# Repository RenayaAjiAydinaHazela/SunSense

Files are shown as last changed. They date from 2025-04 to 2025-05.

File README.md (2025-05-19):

# SunSense : Inovasi Jemuran Cerdas Otomatis untuk Rumah Tangga Modern

> *Matahari bisa absen kapan saja, tapi cucian tetap harus kering !!*
>

<aside>
⛅ Teknologi pintar yang mengikuti perubahan cuaca, menjaga jemuran Anda tetap aman di tengah kondisi tak menentu dan kesibukan yang tak bisa ditinggal

</aside>

## 💡 Tentang SunSense

**SunSense** adalah solusi inovatif untuk pengelolaan jemuran di rumah, mengintegrasikan teknologi otomatisasi dan sensor cerdas untuk menciptakan pengalaman yang lebih efisien, nyaman, dan ramah lingkungan. Dengan menggunakan mikrokontroler dan berbagai sensor, sistem ini dapat secara otomatis mengatur posisi jemuran berdasarkan kondisi cuaca terkini, memberikan kenyamanan ekstra bagi penggunanya.

Saat cuaca cerah dan kering, jemuran akan terbuka secara otomatis untuk mengeringkan pakaian. Sebaliknya, jika cuaca berubah menjadi mendung atau hujan, sistem akan menutup jemuran untuk melindungi pakaian dari hujan. Keunggulan dari **SunSense** adalah fleksibilitas yang diberikan kepada penggunanya; selain otomatis, sistem ini juga bisa dikendalikan secara manual melalui aplikasi atau tombol fisik, sehingga sesuai dengan preferensi pengguna.

Sebagai proyek open-source, **SunSense** terbuka untuk pengembangan lebih lanjut. Dengan pendekatan ini, sistem dapat beradaptasi dengan kebutuhan yang lebih beragam di masa depan, memberi peluang bagi para pengembang untuk berkontribusi dan memperkaya fungsionalitas sistem.

---

## 🎯 Visi dan Misi SunSense

### Visi

Menjadi solusi utama dalam kehidupan rumah tangga modern dengan menghadirkan sistem otomatisasi cerdas yang sederhana, hemat energi, dan mudah diakses oleh semua kalangan, sambil berfokus pada keberlanjutan dan inovasi teknologi.

### Misi

- **Inovasi Berkelanjutan:** Menghadirkan teknologi terbaru yang meningkatkan efisiensi, kenyamanan, dan kualitas hidup sehari-hari melalui otomatisasi rumah tangga.
- **Ramah Lingkungan:** Menyediakan solusi hemat energi yang dapat disesuaikan dengan penggunaan energi terbarukan, membantu rumah tangga mengurangi pemborosan energi.
- **Kolaborasi dengan Komunitas:** Mengembangkan SunSense sebagai proyek open-source yang dapat terus berkembang, dengan melibatkan komunitas untuk menciptakan solusi yang lebih baik dan lebih adaptif.
- **Menyederhanakan Kehidupan Rumah Tangga:** Memberikan kenyamanan lebih dengan otomatisasi jemuran yang merespons perubahan cuaca, sehingga pengguna dapat lebih fokus pada kegiatan mereka tanpa khawatir tentang cuaca yang berubah.
- **Mendorong Pengembangan Teknologi Cerdas:** Memperkenalkan dan memudahkan penerapan teknologi cerdas dalam kehidupan rumah tangga, mengubah rumah biasa menjadi rumah pintar yang lebih efisien dan fungsional.

Dengan pendekatan ini, **visi** dan **misi** SunSense menggabungkan konsep inovasi, ramah lingkungan, otomatisasi, dan kolaborasi komunitas, serta menyoroti pentingnya keberlanjutan dan penggunaan teknologi cerdas untuk meningkatkan kualitas hidup rumah tangga.

---

## 📌 Keunggulan SunSense

**SunSense** bukan hanya sekadar alat otomatis, tetapi sebuah solusi inovatif yang menggabungkan kecanggihan teknologi dan kenyamanan pengguna. Berikut adalah keunggulan utama dari **SunSense**:

1. **Automasi Cerdas yang Responsif**
    
    SunSense dilengkapi dengan sensor canggih yang dapat mendeteksi perubahan cuaca secara real-time. Sistem otomatis akan membuka jemuran saat cuaca cerah dan menutupnya secara otomatis saat hujan atau cuaca buruk, mengurangi kerepotan dalam mengatur jemuran secara manual.
    
2. **Kontrol Manual yang Fleksibel**
    
    Meskipun sepenuhnya otomatis, SunSense tetap memberi kebebasan kepada pengguna untuk mengatur jemuran secara manual kapan saja. Fitur kontrol manual ini memberikan fleksibilitas penuh, memungkinkan pengguna menyesuaikan pengaturan sesuai dengan kebutuhan atau situasi tertentu.
    
3. **Desain Modular dan Dapat Dikembangkan**
    
    SunSense dirancang dengan sistem modular yang memungkinkan pengguna atau pengembang untuk menyesuaikan atau mengembangkan sistem sesuai kebutuhan. Desain ini membuka peluang bagi integrasi dengan perangkat rumah pintar lainnya atau bahkan untuk penggunaan komersial di masa depan.
    
4. **Hemat Energi dan Ramah Lingkungan**
    
    Dengan konsumsi daya yang rendah, SunSense dirancang untuk efisiensi energi. Sistem ini dapat beroperasi dengan sumber daya minimal dan bahkan dapat terintegrasi dengan tenaga surya, menjadikannya pilihan yang lebih ramah lingkungan dan hemat biaya bagi rumah tangga.

Keunggulan-keunggulan ini menjadikan **SunSense** tidak hanya sebagai alat otomatis biasa, tetapi juga solusi yang memberikan kenyamanan lebih, efisiensi energi, dan fleksibilitas yang dapat berkembang sesuai kebutuhan pengguna.

---

## 📈 Potensi Pasar dan Peluang Investasi

**SunSense** memiliki potensi pasar yang besar dalam sektor rumah pintar (smart home) dan teknologi ramah lingkungan. Dengan semakin meningkatnya minat terhadap solusi rumah tangga yang otomatis dan efisien, **SunSense** siap memenuhi kebutuhan masyarakat yang menginginkan cara hidup yang lebih praktis, hemat energi, dan ramah lingkungan.

### Potensi Pasar:

1. **Rumah Tangga di Daerah Tropis atau Beriklim Tidak Menentu**
    
    Di wilayah yang sering mengalami cuaca tak menentu, seperti daerah tropis, **SunSense** akan sangat membantu dalam mengelola jemuran dengan efisien, menghindari kerugian akibat hujan mendadak, dan memastikan pakaian tetap kering tanpa harus tergantung pada cuaca.
    
2. **Layanan Laundry**
    
    Bisnis laundry dapat mengoptimalkan operasional mereka dengan menggunakan **SunSense**. Sistem otomatisasi ini memungkinkan pengelolaan jemuran yang lebih efisien, terutama untuk menanggulangi cuaca buruk, menghemat waktu, dan menjaga kualitas pakaian.
    
3. **Pengguna Rumah Pintar (Smart Homes)**
    
    **SunSense** sangat cocok untuk melengkapi ekosistem rumah pintar. Dengan teknologi otomatisasi yang dapat terintegrasi dengan perangkat rumah pintar lainnya, produk ini menawarkan kemudahan bagi pengguna yang ingin meningkatkan fungsionalitas dan efisiensi energi rumah mereka.
    
4. **Teknologi Hijau dan Energi Terbarukan**
    
    Dengan semakin tingginya kesadaran akan keberlanjutan, **SunSense** dapat menarik minat pasar yang peduli dengan solusi ramah lingkungan. Sistem yang hemat energi dan kompatibel dengan tenaga surya memberikan peluang untuk memperkenalkan teknologi hijau yang mengurangi pemborosan energi.

### Peluang Investasi:

**SunSense** bukan hanya solusi lokal, tetapi memiliki potensi besar untuk berkembang di pasar global. Seiring dengan tren meningkatnya adopsi rumah pintar dan teknologi ramah lingkungan, **SunSense** dapat meraih pangsa pasar yang lebih luas. Peluang investasi di sektor ini juga sangat menarik, karena adanya permintaan yang terus berkembang terhadap solusi yang mengintegrasikan teknologi pintar dengan kehidupan sehari-hari dan mendukung keberlanjutan.

Dengan pendekatan ini, **SunSense** tidak hanya menghadirkan inovasi yang berguna dalam kehidupan sehari-hari, tetapi juga membuka peluang besar untuk berkembang di pasar lokal dan internasional, sambil mendukung tren global menuju rumah pintar dan keberlanjutan energi.

---

## 🎓 In Collaboration With

**Dosen Pengampu :** 
Akhmad Hendriawan S.T., M.T.
197501272002121003

**Mata Kuliah :** 
Mikrokontroller

**Program Studi :** 
D4 Teknik Elektronika 

**Insititusi :** 
Politeknik Elektronika Negeri Surabaya

## 👥 Project Teams

| **NRP** | **Nama** | **Jobdesk** | **Akun** |
| --- | --- | --- | --- |
| 2123600036 | Diqta Putra Aditya |  |  |
| 2123600039 | Jonatan Arya Yoga Pratama |  |  |
| 2123600053 | Naufal Arif Zain |  |  |
| 2123600055 | Renaya Aji Aydina Hazela |  |  |
| 2123600060 | Rahma Aulia Hafidz |  |  |

---

## ✨ Mendukung Pengembangan Bersama

Sebagai proyek open-source, **SunSense** tidak hanya memberikan solusi inovatif bagi pengelolaan jemuran, tetapi juga menawarkan kesempatan bagi para pengembang, inovator, dan komunitas untuk berkolaborasi dalam menciptakan teknologi yang lebih canggih dan terintegrasi. Kolaborasi adalah kunci untuk menghasilkan solusi yang lebih baik, efisien, dan dapat diakses oleh lebih banyak orang.

Dengan mengadopsi prinsip open-source, kami mengundang Anda untuk menjadi bagian dari perjalanan ini, berkontribusi dalam pengembangan **SunSense**, dan membantu mempercepat penerapannya di berbagai sektor kehidupan, mulai dari rumah tangga hingga industri yang membutuhkan solusi efisien dan ramah lingkungan. Semua kontribusi, baik berupa kode, ide, ataupun investasi, akan memperkuat misi kami untuk menciptakan rumah tangga yang lebih efisien dan ramah lingkungan.

### Open-Source dan Kolaborasi Pengembangan

Kami percaya bahwa inovasi terbaik lahir dari kolaborasi. Oleh karena itu, **SunSense** dikembangkan dengan prinsip open-source, memberikan kesempatan kepada pengembang, akademisi, dan para hobiis untuk berkontribusi dalam memperkaya fungsionalitas dan penerapan sistem ini. Dengan pendekatan ini, kami membuka peluang bagi berbagai pihak untuk:

1. **Meningkatkan Fitur**
    
    Pengembang dapat menambahkan fitur baru seperti integrasi dengan perangkat IoT lainnya, atau pengembangan fungsionalitas tambahan yang mendukung kebutuhan rumah tangga modern.
    
2. **Memodifikasi Sistem**
    
    **SunSense** dirancang agar dapat disesuaikan dengan kebutuhan lokal maupun perkembangan teknologi baru. Kontribusi dalam modifikasi sistem akan memungkinkan adaptasi yang lebih luas dan lebih relevan di berbagai lingkungan.
    
3. **Mendorong Inovasi**
    
    Melalui kolaborasi dengan berbagai pihak, baik itu profesional, akademisi, maupun pengembang independen, kami dapat mempercepat proses inovasi dan penerapan teknologi yang ramah lingkungan dan efisien.

Kami mengundang para profesional, pengembang, dan inovator untuk bergabung dalam ekosistem **SunSense**. Bersama-sama, kita dapat menciptakan masa depan rumah tangga yang lebih cerdas, efisien, dan ramah lingkungan.

Dengan pendekatan ini, **SunSense** tidak hanya berfungsi sebagai solusi otomatisasi jemuran, tetapi juga sebagai platform terbuka untuk pengembangan bersama, membuka peluang bagi kolaborasi yang lebih luas dalam menghadirkan teknologi yang lebih baik dan lebih bermanfaat bagi masyarakat.

---

## 📞 Bergabunglah dengan Kami

**SunSense** lebih dari sekadar proyek teknologi, tetapi juga peluang untuk berinvestasi dalam menciptakan masa depan rumah tangga yang lebih cerdas, efisien, dan ramah lingkungan. Kami percaya bahwa kolaborasi adalah kunci untuk membawa inovasi ini ke lebih banyak rumah di seluruh dunia.

Jika Anda tertarik untuk berinvestasi, menjadi mitra, atau sekadar ingin mengetahui lebih banyak tentang **SunSense**, jangan ragu untuk menghubungi kami. Bersama-sama, kita dapat menghadirkan solusi rumah tangga yang lebih praktis dan terhubung dengan teknologi canggih, mendukung keberlanjutan dan efisiensi energi.

Mari wujudkan masa depan rumah tangga yang lebih pintar dan ramah lingkungan dengan bergabung bersama kami. Hubungi kami untuk lebih lanjut dan ambil bagian dalam revolusi rumah tangga pintar.

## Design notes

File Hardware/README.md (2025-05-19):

# 🌞 Hardware SunSense

SunSense dikembangkan sebagai sistem pintar yang mampu merespons kondisi lingkungan secara real-time melalui sensor cahaya, hujan, suhu, dan kelembapan. Dengan memanfaatkan Arduino Nano sebagai otak utama dan modul komunikasi Bluetooth HC-05, proyek ini dirancang untuk memberikan solusi otomatisasi jemuran berbasis cuaca yang praktis dan efisien. 

Sistem ini tidak hanya dapat memantau, tetapi juga melakukan aksi langsung melalui motor servo yang dikendalikan otomatis sesuai data sensor. Pendekatan desain yang kompak, modular, dan berbasis user-experience menjadikan SunSense ideal untuk diterapkan dalam rumah tangga cerdas maupun pengembangan teknologi IoT skala kecil.

---

## ⚙️ Spesifikasi Hardware

| **Komponen** | **Tipe** | **Fungsi** |
| --- | --- | --- |
| **Mikrokontroler** | Arduino Nano | Mikrokontroler utama yang mengelola seluruh proses logika, pengambilan keputusan berdasarkan input sensor. |
| **Sensor Cahaya** | LDR | Mendeteksi intensitas pencahayaan matahari. Digunakan untuk memutuskan kapan jemuran boleh terbuka. |
| **Sensor Hujan** | FC-37 (Rain Drop) | Menentukan keberadaan air/hujan melalui hambatan listrik. Jika mendeteksi hujan (basah), sistem menutup jemuran. |
| **Sensor Suhu**  | DHT22 | Memberikan data suhu dan kelembapan lingkungan sebagai informasi tambahan untuk mengatur kondisi optimal pengeringan. |
| **Motor Servo** | SG90 | Aktuator untuk menggerakkan mekanisme buka-tutup jemuran secara otomatis. |
| **Driver Motor** | L298N | Mengatur suplai daya dan sinyal kontrol ke motor dari mikrokontroler. |
| **Regulator Tegangan** | L7805 | Mengatur dan menstabilkan tegangan 5V dari sumber daya eksternal ke komponen seperti mikrokontroler dan sensor. |
| **Bluetooth Module** | HC-05 | Komunikasi serial jarak dekat untuk kontrol manual dan monitoring via aplikasi mobile. |
| **Power Supply (Baterai)** | Ultrafire 18650A 3000mAh | Menyediakan daya untuk menggerakkan motor dan sistem kontrol secara keseluruhan. |
| **PCB** | Single Layer | Menyusun dan menyambungkan seluruh rangkaian elektronik secara rapi dan terorganisir. |
| **Bearing / Pulley** | - | Mendukung gerakan mekanik agar lebih halus, stabil, dan minim gesekan. |

---

## 📌 Diagram Pin Arduino

| Perangkat | Pin Arduino Nano | Jenis Pin | Keterangan |
| --- | --- | --- | --- |
| LDR | A1 | Analog | Sensor cahaya |
| FC-37 (Sensor Hujan) | D8 | Digital | Sensor hujan |
| DHT22 | D6 | Digital | Suhu & kelembapan |
| Servo Motor | D7 | PWM | Kendali aktuator |
| HC-05 Bluetooth | D0 (TX), D1 (RX) | UART | Komunikasi Serial |

---

## 🔌 Deskripsi Pin dan Fungsi

### 🟢 GPIO Output

### 🧭 Servo Motor

Motor servo dikendalikan melalui **pin D5** menggunakan sinyal **PWM (Pulse Width Modulation)** dari Arduino. Pergerakan servo digunakan untuk **mengoperasikan mekanisme buka-tutup jemuran** secara presisi dan otomatis. Keputusan penggerakan servo didasarkan pada hasil analisis data dari sensor lingkungan, seperti hujan, suhu, dan intensitas cahaya, guna memastikan jemuran hanya terbuka pada kondisi cuaca yang aman dan optimal.

---

### 🔁 UART Communication

### 📶 HC-05 (Bluetooth Module)

Modul HC-05 dihubungkan ke pin **D0 (TX)** dan **D1 (RX)** Arduino, memungkinkan komunikasi **serial dua arah** antara sistem dan aplikasi pada perangkat seluler. Modul ini berfungsi sebagai antarmuka **nirkabel** yang memudahkan pengguna untuk **memantau status sensor secara real-time** serta **mengontrol sistem jemuran otomatis** langsung dari jarak dekat melalui koneksi Bluetooth. Integrasi ini meningkatkan fleksibilitas dan kemudahan dalam pengoperasian sistem.

---

### 📥 Analog Input

### 🟡 LDR (Light Dependent Resistor)

Sensor LDR terhubung ke pin **A1** dan menghasilkan sinyal **analog** yang merepresentasikan intensitas pencahayaan lingkungan. Arduino membaca perubahan tegangan dalam rentang **0–5V** dan menginterpretasikannya sebagai indikator cuaca cerah atau mendung. Nilai ini digunakan sistem untuk membantu menentukan apakah jemuran otomatis perlu **dibuka atau ditutup**, berdasarkan ambang batas pencahayaan yang telah diprogram

### 📥 Digital Input

---

### 🌧️ FC-37 (Sensor Hujan)

Sensor hujan FC-37 dihubungkan ke pin **D8** dan memberikan sinyal digital berupa **HIGH** atau **LOW** berdasarkan kondisi permukaan sensornya. Ketika permukaan sensor dalam kondisi **basah**, output akan **LOW**, dan ketika **kering**, output akan **HIGH**. Informasi ini digunakan sistem sebagai indikator otomatis untuk mendeteksi keberadaan hujan dan mengaktifkan mekanisme penutupan jemuran.

### 🌡️ DHT22 (Sensor Suhu & Kelembapan)

Terhubung ke pin **D6**, sensor DHT22 menggunakan protokol komunikasi **single-wire (*One-Wire*)** untuk mengirimkan data suhu dan kelembapan secara berkala. Informasi lingkungan ini menjadi parameter pendukung yang penting dalam sistem pengambilan keputusan, guna memastikan proses pengeringan berjalan pada kondisi yang optimal dan efisien.

---

## 📦 Library Arduino

Instal melalui Library Manager di Arduino IDE:

- `DHT sensor library`
- `Adafruit Unified Sensor`
- `Servo.h` – Tersedia secara default di Arduino IDE

---

## 🏷️ Lisensi

Proyek ini merupakan inovasi berbasis mikrokontroler yang dikembangkan secara mandiri oleh mahasiswa **Electronic Engineering Polytechnic Institute of Surabaya (EEPIS)** untuk menjawab kebutuhan otomatisasi rumah tangga yang cerdas dan efisien. 
SunSense dirancang dengan pendekatan teknis yang solid, menggunakan sensor cuaca dan aktuator presisi untuk mendeteksi kondisi lingkungan secara real-time dan mengoperasikan sistem jemuran otomatis.

Proyek ini terbuka untuk dikembangkan lebih lanjut dan dapat dimodifikasi untuk kebutuhan komersial maupun edukatif, selama tetap mencantumkan sumber. Dengan pendekatan modular, efisien, dan berbasis data, SunSense menjadi solusi potensial dalam pengembangan smart home berbasis teknologi lokal yang scalable dan dapat diandalkan.

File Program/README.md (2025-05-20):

# 🌤️ **Program SunSense**

## 📋 **Deskripsi Program Simulasi**

Program ini merupakan bagian dari pengembangan sistem **SunSense**, yaitu solusi jemuran cerdas yang mampu beradaptasi terhadap kondisi lingkungan secara **otomatis maupun manual** menggunakan platform mikrokontroler **Arduino Nano**.

Simulasi ini dibangun di **Wokwi**, sebuah simulator online berbasis Arduino, dengan tujuan untuk **mengujicoba logika dan alur kerja sistem** sebelum diterapkan ke perangkat keras sesungguhnya.

Beberapa komponen fisik digantikan dengan **potensiometer** dan **push button** agar fleksibel dalam pengujian berbagai skenario lingkungan seperti suhu tinggi, cahaya rendah, atau kondisi hujan.

> Fokus utama simulasi: Menguji keakuratan pengambilan keputusan, kestabilan logika servo, serta validitas data yang dikirim via komunikasi serial.
> 

---

## 🗂️ **Struktur Program**

- **🔬 Program Simulasi (Prototype Virtual)**
    
    Menggunakan komponen pengganti untuk mencerminkan perilaku sensor asli. Simulasi ini menguji logika pengendalian servo dan pengambilan keputusan berdasarkan parameter lingkungan.
    
- **🔧 Program Asli Hardware (Final Deployment)** 
    
    Dirancang untuk implementasi fisik dengan koneksi sensor dan aktuator asli, termasuk penggunaan **DHT22**, **FC-37**, **LDR**, serta **HC-05** untuk integrasi mobile app melalui Bluetooth.

---

## 🛠️ **Komponen Simulasi di Wokwi**

| Komponen | Fungsi | Keterangan |
| --- | --- | --- |
| **Potensiometer 1** | Simulasi suhu lingkungan | Output analog dikonversi menjadi nilai suhu (rentang 0–50°C) |
| **Potensiometer 2** | Simulasi intensitas cahaya | Mewakili nilai dari sensor LDR, digunakan untuk deteksi siang/malam |
| **Potensiometer 3** | Simulasi kelembapan udara | Input analog dikonversi menjadi % kelembapan |
| **Push Button 1** | Simulasi kondisi hujan | Nilai LOW = hujan; HIGH = tidak hujan |
| **Push Button 2** | Pergantian mode otomatis <-> manual | Ditekan sekali untuk mengubah mode kerja |
| **Push Button 3** | Kontrol manual jemuran | Aktif hanya saat berada di mode manual |
| **Servo Motor** | Simulasi aktuator penggerak jemuran | Digerakkan ke posisi 0° (masuk) atau 45° (keluar) |

> Kombinasi potensiometer dan tombol memungkinkan simulasi dinamis terhadap perubahan lingkungan dan intervensi pengguna.
> 

---

## 🔌 **Konfigurasi Pin: Simulasi vs Hardware**

### 🔧 Simulasi (Wokwi)

| Perangkat Simulasi | Pin Arduino | Tipe Pin | Fungsi dalam Simulasi |
| --- | --- | --- | --- |
| Potensiometer 1 | A0 | Analog | Suhu |
| Potensiometer 2 | A1 | Analog | Cahaya (LDR) |
| Potensiometer 3 | A2 | Analog | Kelembapan |
| Push Button 1 (Biru) | D2 | Digital | Hujan |
| Push Button 2 (Merah) | D3 | Digital | Ganti mode |
| Push Button 3 (Hijau)| D4 | Digital | Kontrol manual |
| Servo Motor | D5 | PWM | Aktuator jemuran |

### ⚙️ Hardware (Final)

| Perangkat Asli | Pin Arduino Nano | Tipe Pin | Keterangan |
| --- | --- | --- | --- |
| LDR (Sensor Cahaya) | A1 | Analog | Mengukur intensitas pencahayaan |
| FC-37 (Sensor Hujan) | D8 | Digital | Deteksi permukaan basah/kering |
| DHT22 | D6 | Digital | Mengukur suhu & kelembapan |
| Servo Motor | D7 | PWM | Menggerakkan mekanisme jemuran |
| HC-05 Bluetooth | D0 (TX), D1 (RX) | UART | Komunikasi dengan mobile app |

---

## 🧠 **Alur Logika Program**

Alur program pada sistem SunSense terbagi menjadi **5 tahap utama** yang berlangsung secara berulang (loop) selama sistem berjalan. Masing-masing tahap dijelaskan lebih detail berikut ini:

---

### 🟢 **1. Pembacaan Sensor Simulasi**

Sistem membaca data dari tiga potensiometer sebagai pengganti sensor fisik:

- **Potensiometer 1 (A0):**
    - Disimulasikan sebagai **suhu lingkungan**.
    - Nilai analog (0–1023) dikonversi ke skala suhu (sekitar 0–50°C) menggunakan rumus linear.
    - Tujuannya untuk meniru pembacaan dari sensor **DHT22** atau **LM35**.
- **Potensiometer 2 (A1):**
    - Disimulasikan sebagai **intensitas cahaya** (LDR).
    - Nilai analog tinggi → cahaya terang, nilai rendah → cahaya gelap.
    - Threshold digunakan untuk menentukan siang atau malam.
- **Potensiometer 3 (A2):**
    - Disimulasikan sebagai **kelembapan udara**.
    - Dikonversi ke skala kelembapan (0–100%).
    - Mewakili kemampuan udara untuk menahan uap air, berkaitan dengan potensi hujan atau penguapan.

🔄 *Pembacaan dilakukan secara terus-menerus setiap siklus loop untuk menangkap perubahan kondisi lingkungan secara real time.*

---

### 🟨 **2. Pembacaan Input Push Button**

Sistem menggunakan **tiga push button digital** untuk mengontrol dan menyimulasikan peristiwa:

- **Push Button 1 (D2) – Deteksi Hujan:**
    - Jika ditekan (LOW), maka sistem mendeteksi bahwa **hujan sedang turun**.
    - Jika tidak ditekan (HIGH), maka cuaca dianggap **kering**.
    - Ini meniru pembacaan digital dari sensor **FC-37** yang mendeteksi tetesan air.
- **Push Button 2 (D3) – Toggle Mode Otomatis/Manual:**
    - Menekan tombol ini akan **mengubah mode kerja** sistem secara *toggle*:
        - Jika sebelumnya **otomatis**, maka berubah ke **manual**.
        - Jika sebelumnya **manual**, kembali ke **otomatis**.
    - Digunakan `flag` (variabel penanda) untuk menyimpan status mode saat ini.
- **Push Button 3 (D4) – Kontrol Manual:**
    - Hanya aktif saat berada dalam **mode manual**.
    - Jika ditekan → jemuran **keluar** (servo ke 45°).
    - Jika dilepas → jemuran **masuk** (servo ke 0°).
    - Simulasi ini memberi pengguna kontrol langsung atas jemuran, seperti **override** otomatis.

---

### 🟧 **3. Logika Keputusan Sistem (Decision Making)**

### 🔁 **Jika Mode Otomatis Aktif:**

Sistem akan **menganalisis parameter lingkungan** untuk menentukan apakah jemuran sebaiknya dikeluarkan atau dimasukkan:

| Parameter | Nilai Ideal | Keterangan |
| --- | --- | --- |
| Suhu | > 30°C | Semakin tinggi suhu, semakin baik untuk pengeringan pakaian |
| Cahaya | > 300 (dari 1023) | Menandakan siang hari (terang), cocok untuk menjemur |
| Kelembapan | < 80% | Kelembapan rendah → udara kering → mempercepat pengeringan |
| Deteksi Hujan | Tidak hujan (HIGH) | Jika ada hujan → jemuran wajib masuk tanpa mempedulikan parameter lain |

**Logika gabungan (AND):**

```c
if (suhu > 30 && cahaya > 300 && kelembapan < 80 && !hujan) {
    // jemuran keluar
} else {
    // jemuran masuk
}
```

📌 **Catatan penting:**

Jika **salah satu saja** dari syarat di atas tidak terpenuhi, sistem akan memutuskan untuk **memasukkan jemuran** demi keamanan.

---

### ⛔ **Jika Mode Manual Aktif:**

- Sistem **mengabaikan semua data sensor**, termasuk deteksi hujan.
- **Keputusan hanya diambil dari tombol push button 3:**
    - Tekan → jemuran keluar.
    - Lepas → jemuran masuk.
- Cocok untuk kondisi tertentu di mana pengguna ingin mengambil alih kontrol sepenuhnya (misalnya, menjemur sepatu atau pakaian khusus dalam cuaca ekstrem tapi mendesak).

---

### 🟦 **4. Pengendalian Aktuator (Servo Motor)**

Servo motor digunakan untuk mensimulasikan pergerakan jemuran dengan dua posisi utama:

| Posisi Servo | Sudut | Aksi Jemuran |
| --- | --- | --- |
| 0° | MINIMAL | Jemuran masuk |
| 45° | TERBUKA | Jemuran keluar |

### 🔄 Alur Pengendalian:

- Program hanya akan **menggerakkan servo** jika posisi saat ini berbeda dari posisi sebelumnya untuk menghindari getaran servo yang tidak perlu (hemat energi & memperpanjang umur servo).

```c
if (statusSekarang != statusSebelumnya) {
   servo.write(sudutBaru);
}
```

---

### 📤 **5. Pengiriman Data ke Serial Monitor**

Semua data penting akan ditampilkan di **Serial Monitor** untuk tujuan debugging, pemantauan, dan dokumentasi logika sistem.

**Data yang dikirim meliputi:**

- Nilai suhu dalam °C
- Nilai kelembapan dalam %
- Nilai cahaya (0–1023)
- Status hujan (Ya/Tidak)
- Mode aktif (Otomatis/Manual)
- Aksi jemuran (Keluar/Masuk)

📦 Format contoh di Serial Monitor:

```
Mode: Otomatis
Suhu: 32.5 °C
Kelembapan: 65.3 %
Cahaya: 540
Status Hujan: Tidak
Jemuran: Keluar
-----------------------------
```
Data ini juga dapat dimanfaatkan pada tahap selanjutnya untuk **dikirim ke aplikasi mobile** via Bluetooth HC-05 dalam implementasi hardware.

---

## 🔍 **Threshold Logika Otomatis (Contoh)**

| Parameter | Ambang Batas | Keputusan Sistem |
| --- | --- | --- |
| Suhu | > 30°C | Jemuran dapat keluar |
| Intensitas Cahaya | > 300 (analog) | Siang, jemuran dapat keluar |
| Kelembapan | < 80% | Aman untuk menjemur |
| Status Hujan | Tidak hujan | Jemuran dapat keluar |

> Jika salah satu parameter tidak memenuhi, jemuran akan masuk otomatis untuk perlindungan.
> 

---

## 📡 **Integrasi ke Perangkat Mobile (Tahap Hardware)**

- Komunikasi dua arah menggunakan **HC-05 Bluetooth**.
- Data suhu, kelembapan, kondisi hujan, dan status jemuran ditampilkan di aplikasi mobile.
- Pengguna juga bisa mengganti mode dan mengontrol jemuran dari aplikasi.

---

## 💻 **Simulasi Online**
   
   👉 [Klik di sini untuk membuka simulasi di Wokwi](https://wokwi.com/projects/429473945254121473)

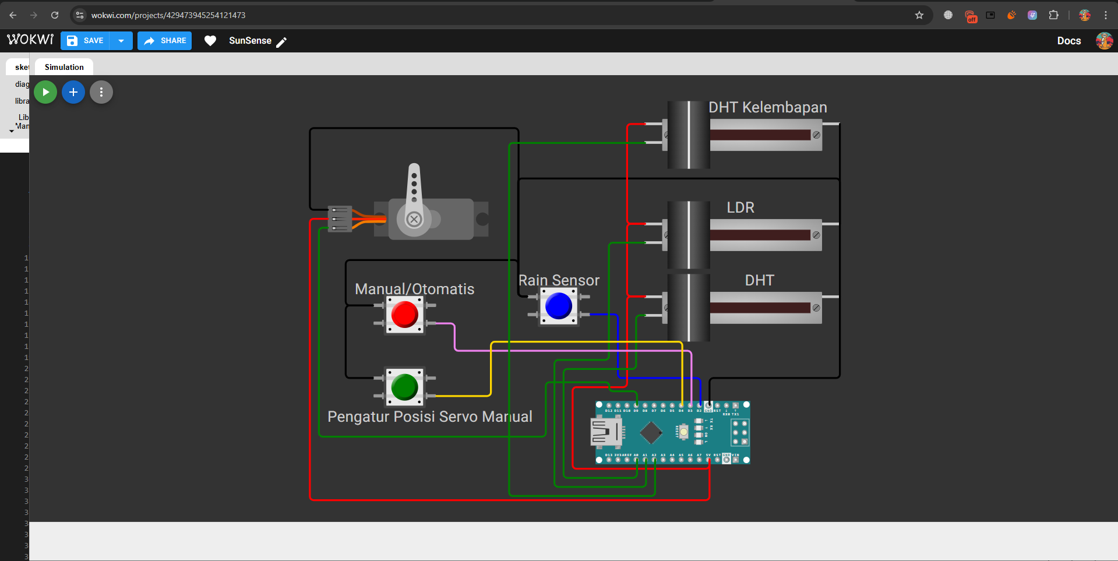
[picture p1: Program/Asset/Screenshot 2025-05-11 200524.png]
  
  
---

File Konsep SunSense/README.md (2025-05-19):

# ⛅ Konsep SunSense

SunSense adalah solusi cerdas untuk aktivitas menjemur pakaian yang menggabungkan teknologi otomasi dengan responsivitas terhadap cuaca secara *real-time*. Dirancang untuk merespons tantangan harian seperti hujan mendadak atau cuaca tak menentu, sistem ini secara otomatis membuka dan menutup jemuran sesuai kondisi lingkungan, tanpa perlu intervensi pengguna.

Lebih dari sekadar alat bantu, SunSense membawa pendekatan baru dalam mengelola rutinitas rumah tangga secara lebih **efisien, praktis, dan modern**. Sistem ini dikembangkan sebagai jawaban atas kebutuhan gaya hidup yang semakin dinamis, di mana waktu, kenyamanan, dan ketepatan menjadi prioritas.

Dengan desain yang dapat diadaptasi untuk skala rumah tangga maupun kebutuhan komersial seperti usaha laundry, SunSense menawarkan lebih dari kemudahan. Kehadiran SunSense akan  menjadi bagian dari transformasi menuju **rumah pintar** (*smart living*) yang berdaya guna dan hemat energi.

Konsep ini juga terbuka untuk pengembangan lebih lanjut, seperti integrasi dengan Internet of Things (IoT) dan kontrol berbasis aplikasi, menjadikannya fleksibel untuk masa kini dan siap menghadapi kebutuhan masa depan.

---

## ⚙️ Komponen Utama Sistem SunSense

SunSense dibangun dari serangkaian komponen utama yang saling terintegrasi dan memiliki peran spesifik dalam mendeteksi, mengolah, serta merespons kondisi cuaca. Setiap komponen dipilih berdasarkan pertimbangan efisiensi, kinerja, dan kemudahan integrasi, sehingga sistem tidak hanya bekerja optimal, tetapi juga mudah dikembangkan lebih lanjut.

| **Komponen** | **Tipe** | **Fungsi** | Harga |
| --- | --- | --- | --- |
| **Mikrokontroler** | Arduino Nano | Mikrokontroler utama yang mengelola seluruh proses logika, pengambilan keputusan berdasarkan input sensor. |  |
| **Sensor Cahaya** | LDR | Mendeteksi intensitas pencahayaan matahari. Digunakan untuk memutuskan kapan jemuran boleh terbuka. | 10.000 |
| **Sensor Hujan** | FC-37 (Rain Drop) | Menentukan keberadaan air/hujan melalui hambatan listrik. Jika mendeteksi hujan (basah), sistem menutup jemuran. | 20.000 |
| **Sensor Suhu**  | DHT22 | Memberikan data suhu dan kelembapan lingkungan sebagai informasi tambahan untuk mengatur kondisi optimal pengeringan. | 15.000 |
| **Motor Servo** | SG90 | Aktuator untuk menggerakkan mekanisme buka-tutup jemuran secara otomatis. | 50.000 |
| **Driver Motor** | L298N | Mengatur suplai daya dan sinyal kontrol ke motor dari mikrokontroler. | 25.000 |
| **Regulator Tegangan** | L7805 | Mengatur dan menstabilkan tegangan 5V dari sumber daya eksternal ke komponen seperti mikrokontroler dan sensor. | 50.000 |
| **Bluetooth Module** | HC-05 / HC-06 | Komunikasi serial jarak dekat untuk kontrol manual dan monitoring via aplikasi mobile. | 40.000 |
| **Power Supply** | - | Menyediakan daya untuk menggerakkan motor dan sistem kontrol secara keseluruhan. | 50.000 |
| **PCB** | - | Menyusun dan menyambungkan seluruh rangkaian elektronik secara rapi dan terorganisir. | 20.000 |
| **Bearing / Pulley** | - | Mendukung gerakan mekanik agar lebih halus, stabil, dan minim gesekan. |  |

Tak hanya berfokus pada kecanggihan sensor dan kendali otomatis, SunSense juga mengedepankan stabilitas sistem secara menyeluruh. Desainnya memperhatikan keteraturan sirkuit elektronik agar lebih aman dan efisien, sekaligus memastikan pergerakan mekanik berjalan dengan lancar tanpa hambatan berarti. 

Sistem penggeraknya didukung oleh komponen perantara yang menjamin instruksi dari unit kendali dapat diterjemahkan dengan presisi ke gerakan fisik yang diharapkan. Kombinasi antara aspek elektronik dan mekanik ini menjadikan SunSense tidak hanya andal, tetapi juga siap untuk dikembangkan ke skala lebih besar.

---

## 📋 Komunikasi Sistem

Agar dapat bekerja secara otomatis namun tetap adaptif terhadap kebutuhan pengguna, sistem SunSense mengandalkan skema komunikasi data yang tertata antara berbagai komponen internal maupun eksternal. Komunikasi ini mencakup tiga jalur utama: sensor ke mikrokontroler, mikrokontroler ke aktuator, serta mikrokontroler ke pengguna. Masing-masing jalur memiliki karakteristik dan fungsi tersendiri yang saling terintegrasi dalam kerangka kendali tertanam (*embedded control system*).

### Sensor ke Mikrokontroler (*One-Way Input*)

Sensor-sensor lingkungan berfungsi sebagai “mata dan telinga” sistem, memberikan informasi aktual terkait kondisi sekitar secara real-time. Komunikasi dari sensor ke mikrokontroler bersifat satu arah, di mana sensor mengirimkan sinyal:

- **Analog**, seperti pada sensor cahaya (LDR) atau sensor suhu, yang mengirimkan nilai kontinu untuk merepresentasikan intensitas cahaya atau suhu ruangan.
- **Digital**, seperti pada sensor hujan, yang memberikan status biner (hujan atau tidak) sebagai logika keputusan cepat.

Mikrokontroler kemudian membaca data ini melalui pin analog atau digital, lalu mengolahnya untuk menentukan kondisi cuaca saat itu.

### Mikrokontroler ke Aktuator (*One-Way Output*)

Setelah data dari sensor diproses dan dikonversi menjadi instruksi, mikrokontroler mengirimkan perintah kepada aktuator (motor penggerak) untuk mengeksekusi tindakan fisik. Komunikasi ini juga bersifat satu arah, dengan pola sebagai berikut:

- **Sinyal PWM (Pulse Width Modulation)** digunakan untuk mengatur kecepatan atau posisi motor, tergantung jenis motor yang digunakan (servo atau DC).
- **Transmisi sinyal logika melalui driver** untuk memastikan arus dan tegangan sesuai kebutuhan aktuator, menjaga keamanan rangkaian dan efektivitas perintah.

Perintah yang dikirim bisa berupa instruksi membuka atau menutup jemuran, tergantung pada hasil analisis kondisi cuaca.

### Mikrokontroler ke Pengguna (Two-*Way*)

Salah satu nilai tambah SunSense adalah kemampuannya untuk tetap terkoneksi dengan pengguna melalui jalur komunikasi eksternal berbasis Bluetooth. Jalur ini memungkinkan komunikasi dua arah:

- **Arah keluar (output):** Mikrokontroler mengirimkan informasi status sistem, seperti kondisi cuaca terkini, posisi jemuran, atau peringatan kesalahan.
- **Arah masuk (input):** Pengguna dapat mengirim perintah override secara manual melalui aplikasi di smartphone, misalnya jika ingin menutup jemuran lebih awal atau membukanya meski sensor menunjukkan cuaca buruk.

Fleksibilitas ini menjadikan SunSense tidak hanya sepenuhnya otomatis, tetapi juga adaptif terhadap preferensi dan keputusan pengguna saat diperlukan.

### Integrasi Komunikasi

Ketiga jalur komunikasi ini bekerja secara sinergis untuk membentuk sistem kendali tertutup yang responsif, namun terbuka untuk intervensi manual. Secara default, SunSense akan menjalankan operasi berbasis data sensor (autonomous mode). Namun, pengguna tetap diberi ruang untuk mengambil kendali jika terdapat kondisi khusus di luar parameter yang telah ditentukan sistem.

Pola komunikasi ini juga dirancang untuk mendukung pengembangan lebih lanjut, seperti integrasi ke sistem IoT melalui koneksi Wi-Fi atau cloud monitoring, menjadikan SunSense sebagai sistem jemuran pintar yang benar-benar relevan untuk masa depan rumah tangga dan industri modern.

---

## 🔎 Fitur Utama SunSense

SunSense tidak hanya menawarkan solusi praktis untuk menjemur pakaian secara otomatis, tetapi juga mengusung prinsip efisiensi, adaptabilitas, dan kenyamanan pengguna. Fitur-fitur unggulan berikut dirancang untuk memastikan pengalaman penggunaan yang cerdas, hemat energi, dan dapat diandalkan dalam berbagai kondisi :

### Otomatisasi Berbasis Cuaca

Sistem secara mandiri mendeteksi intensitas cahaya matahari dan keberadaan hujan untuk menentukan kapan jemuran perlu dibuka atau ditutup. Proses ini bekerja tanpa campur tangan pengguna, menciptakan kenyamanan dan mengurangi risiko pakaian basah akibat cuaca yang berubah mendadak.

### Pemantauan Lingkungan *Real-Time*

Sensor suhu dan kelembaban memberikan data lingkungan yang akurat dan kontinu. Informasi ini menjadi acuan dalam proses pengambilan keputusan otomatis sistem, misalnya mengatur waktu buka/tutup yang lebih adaptif terhadap kondisi aktual, serta memberi potensi untuk fitur prediksi pengeringan optimal.

### **Kontrol Manual melalui Konektivitas Bluetooth**

Pengguna tetap dapat mengakses dan mengendalikan sistem secara manual melalui aplikasi berbasis Bluetooth. Fungsi ini memberikan fleksibilitas tinggi, memungkinkan override saat pengguna menginginkan kontrol penuh di luar keputusan otomatis sistem.

### **Sistem Fail-Safe untuk Kondisi Darurat**

SunSense dilengkapi dengan logika fail-safe, di mana sistem akan menutup jemuran secara otomatis saat terjadi kegagalan pendeteksian sensor atau kondisi daya lemah. Ini menjaga pakaian tetap aman dan melindungi perangkat dari kerusakan akibat pengoperasian dalam kondisi tidak ideal.

### **Efisiensi Energi dan Dukungan Energi Terbarukan**

Dengan rancangan hemat daya, SunSense dapat dioperasikan menggunakan sumber energi alternatif seperti panel surya. Arsitektur sistem mengutamakan efisiensi dalam konsumsi daya, menjadikannya ideal untuk penggunaan berkelanjutan dalam jangka panjang, bahkan di lokasi dengan akses listrik terbatas.

---

## 📑 Pengembangan Selanjutnya untuk SunSense

SunSense dirancang untuk menjadi platform yang modular dan dapat berkembang, dengan berbagai potensi pengembangan di masa depan. Dengan pengembangan-pengembangan ini, SunSense akan semakin fleksibel dan canggih, memberikan lebih banyak manfaat bagi penggunanya, baik di rumah maupun dalam aplikasi komersial. Beberapa arah pengembangan yang direncanakan adalah sebagai berikut:

### **Integrasi IoT dan WiFi (ESP32/ESP8266)**

SunSense dapat dihubungkan dengan ekosistem rumah pintar (smart home) melalui integrasi dengan perangkat IoT seperti ESP32 atau ESP8266. Dengan koneksi WiFi, pengguna bisa mengendalikan perangkat SunSense secara jarak jauh, baik melalui aplikasi mobile ataupun platform berbasis cloud. Ini memungkinkan kontrol yang lebih praktis dan otomatisasi dalam pengelolaan jemuran.

### **Sistem Notifikasi Otomatis**

SunSense akan dilengkapi dengan kemampuan untuk memberi pemberitahuan kepada pengguna melalui smartphone. Misalnya, jika jemuran tiba-tiba tertutup karena hujan atau suhu ekstrem, pengguna akan menerima notifikasi langsung di ponsel mereka. Fitur ini akan sangat membantu untuk memastikan pakaian tetap aman dan kering, serta menghindari kerusakan akibat cuaca buruk.

### **Sumber Energi Berkelanjutan**

Dengan menambahkan sistem tenaga surya dan manajemen baterai (BMS), SunSense dapat berfungsi sepenuhnya tanpa bergantung pada sumber daya listrik dari jaringan (off-grid). Ini akan membuat SunSense lebih ramah lingkungan dan mengurangi ketergantungan pada energi dari luar, menjadikannya solusi yang lebih efisien dan mandiri, ideal untuk daerah-daerah yang sulit dijangkau oleh listrik.

### **Integrasi Kamera atau Sensor UV**

Untuk meningkatkan kualitas pengeringan, SunSense dapat dilengkapi dengan kamera atau sensor UV. Sensor ini akan mengukur intensitas sinar ultraviolet (UV) yang dapat memengaruhi pakaian tertentu, memberikan perlindungan tambahan bagi pakaian yang sensitif terhadap paparan sinar UV, atau bahkan memberikan data yang lebih akurat mengenai kondisi pengeringan.

### **Modul AI Ringan**

SunSense akan menggunakan teknologi micro-AI yang mampu memprediksi cuaca berdasarkan pola historis dan data cuaca real-time dari API eksternal. Dengan modul AI ini, SunSense bisa lebih cerdas dalam memprediksi kondisi cuaca dan menyesuaikan pengeringan sesuai dengan prediksi tersebut, meningkatkan efisiensi dan kenyamanan penggunaan.

### **Versi Komersial (Industrial Grade)**

Untuk memenuhi kebutuhan fasilitas komersial seperti hotel, laundry besar, atau fasilitas umum lainnya, SunSense akan memiliki versi industrial-grade. Versi ini akan dilengkapi dengan rangkaian motor yang lebih kuat, kontrol yang lebih terpusat, dan struktur yang tahan terhadap cuaca ekstrem, menjadikannya solusi yang lebih tahan lama dan dapat diandalkan untuk penggunaan skala besar.

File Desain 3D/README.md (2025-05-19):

# Visualisasi Desain 3D Proyek SunSense

Desain 3D SunSense bukan sekadar visualisasi estetika, tetapi representasi teknis dari rancangan produk yang siap diproduksi dan digunakan di kehidupan nyata. Model ini dirancang secara detail untuk menggambarkan integrasi antara komponen elektronik, aktuator mekanis, serta struktur fisik tempat jemuran otomatis beroperasi.

Setiap aspek desain telah dipertimbangkan secara fungsional. Dimensi motor servo, posisi sumbu putar jemuran, hingga penempatan sensor hujan dan cahaya disusun agar mendukung efektivitas pembacaan data serta efisiensi pergerakan mekanis. Rangka didesain ringan namun kokoh, dengan struktur penyangga yang memudahkan instalasi baik untuk penggunaan rumah tangga maupun kebutuhan industri skala kecil.

Desain ini juga memperhitungkan kemudahan dalam perawatan dan penggantian komponen. Sirkuit terintegrasi pada PCB yang ditempatkan secara aman dan terorganisir, sementara komponen pendukung seperti bearing dan pulley digunakan untuk menjamin kelancaran dan stabilitas gerak. Semua ini divisualisasikan dalam desain 3D secara realistis, memungkinkan investor maupun mitra teknis untuk melihat potensi produk dengan presisi yang tinggi bahkan sebelum prototipe fisik dibuat.

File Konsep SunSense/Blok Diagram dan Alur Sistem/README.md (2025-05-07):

# Alur Sistem SunSense

Diagram blok di atas menggambarkan skema kerja utama sistem otomatisasi jemuran **SunSense**, yang terintegrasi antara input daya, komponen sensorik, kendali mikrokontroler, dan sistem aktuator serta kontrol pengguna melalui antarmuka digital. Penjabaran alurnya sebagai berikut:

## **Sumber Daya dan Inisialisasi Sistem**

Sistem menggunakan **baterai Li-ion 18650** sebagai sumber daya utama yang efisien dan dapat diisi ulang. Ketika sistem pertama kali diaktifkan, **mikrokontroler (Arduino Nano)** akan langsung menjalankan proses inisialisasi—mengaktifkan komunikasi dengan seluruh sensor serta modul Bluetooth.

## **Pemantauan Lingkungan Secara Real-Time**

Setelah inisialisasi, Arduino mulai membaca data dari ketiga sensor utama:

- **Sensor Suhu dan Kelembaban (DHT11/22)** untuk mengetahui kondisi termal dan kelembaban udara.
- **Sensor Cahaya (LDR)** untuk mendeteksi intensitas cahaya sekitar.
- **Sensor Hujan (Raindrop Module)** untuk mengetahui adanya curah hujan secara langsung.

Seluruh data dari sensor ini dikirimkan ke mikrokontroler melalui jalur analog maupun digital, tergantung jenis sensornya.

## **Pengolahan Data dan Pengambilan Keputusan**

Mikrokontroler memproses input dari sensor menggunakan logika terprogram. Contoh alur logikanya:

- Jika kondisi **cerah dan tidak hujan**, maka sistem membuka jemuran.
- Jika **terdeteksi hujan**, atau **kelembaban tinggi dan suhu rendah**, maka sistem menutup jemuran.
- Keputusan ini diambil secara dinamis berdasarkan ambang batas (threshold) yang telah ditentukan di dalam kode program.

## **Aktuasi Sistem Mekanis**

Setelah logika keputusan terbentuk, Arduino mengirim sinyal ke **aktuator (motor servo)**. Aktuator ini bertugas menggerakkan rangka jemuran untuk membuka atau menutup, sesuai perintah yang diberikan.

## **Kontrol Eksternal via Bluetooth**

Pengguna memiliki akses ke sistem melalui **modul Bluetooth HC-05**, yang terhubung ke aplikasi GUI pada smartphone. Melalui antarmuka ini:

- Pengguna dapat **memantau status sensor** secara real-time.
- Sistem dapat di-**override** (kontrol manual) jika pengguna ingin membuka atau menutup jemuran sesuai preferensi, misalnya untuk mempercepat proses pengeringan meskipun cuaca kurang mendukung.

## **Sistem Siaga dan Penghematan Energi**

Setelah aktuasi selesai, sistem akan masuk ke mode **standby** untuk menghemat energi. Mikrokontroler hanya akan aktif kembali jika sensor mendeteksi perubahan kondisi lingkungan secara signifikan, misalnya, perubahan dari cerah ke mendung atau mulai turunnya hujan.

Melalui alur kerja ini, SunSense menawarkan solusi otomasi yang adaptif dan hemat energi, dengan dukungan kontrol manual yang fleksibel. Kombinasi komunikasi data internal (sensor ke mikrokontroler) dan eksternal (mikrokontroler ke pengguna) menjadikan sistem ini cerdas, efisien, dan ramah pengguna.

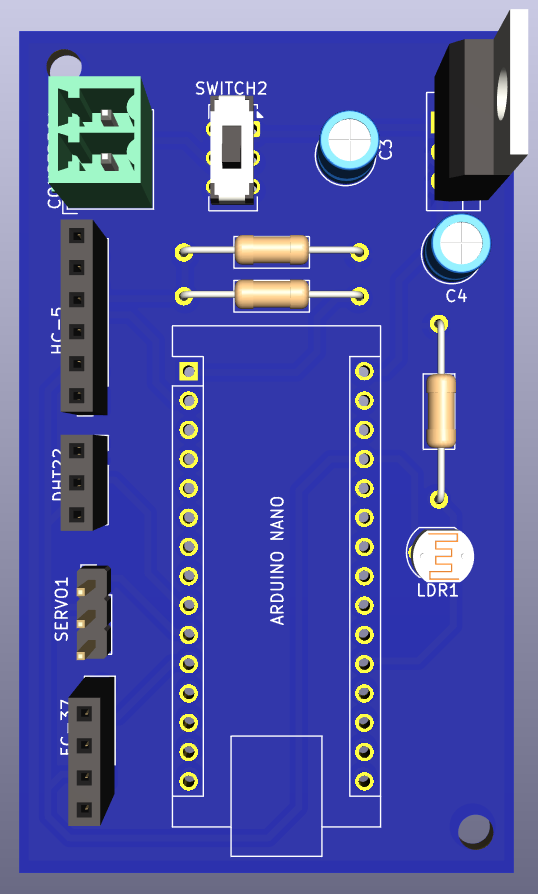
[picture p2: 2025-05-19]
Hardware/KiCad/3D Design/3D Design from Board SunSense (front).png

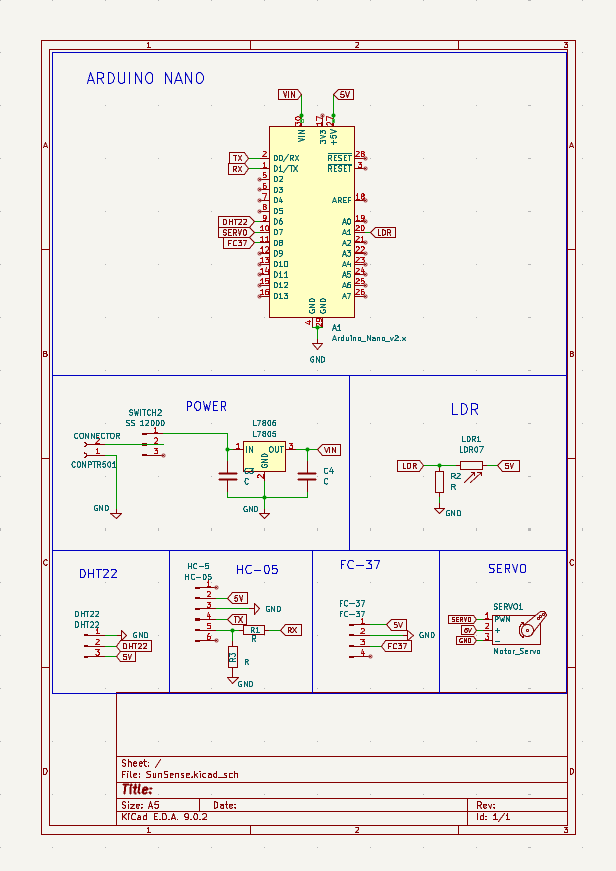
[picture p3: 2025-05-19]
Hardware/KiCad/Schematic/Schematic KiCad.png

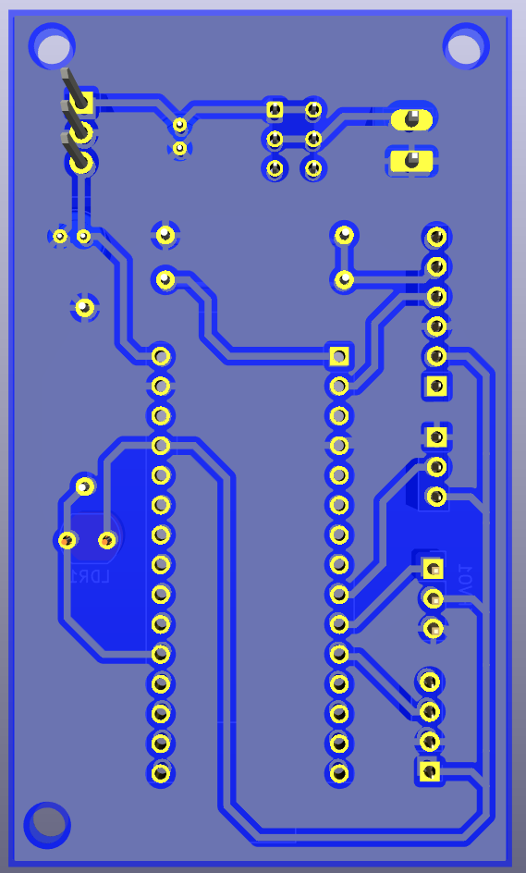
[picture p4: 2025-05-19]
Hardware/KiCad/3D Design/3D Design from Board SunSense (behind).png

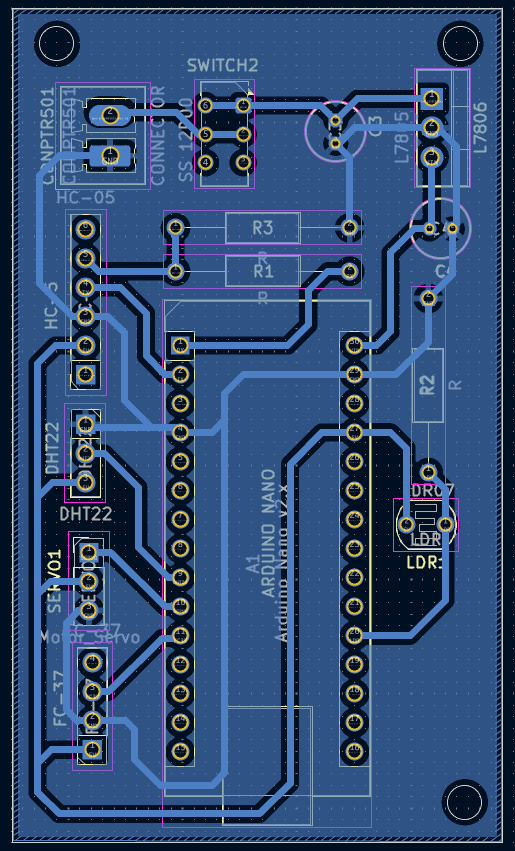
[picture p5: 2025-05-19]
Hardware/KiCad/Board/PCB Layout SunSense.png

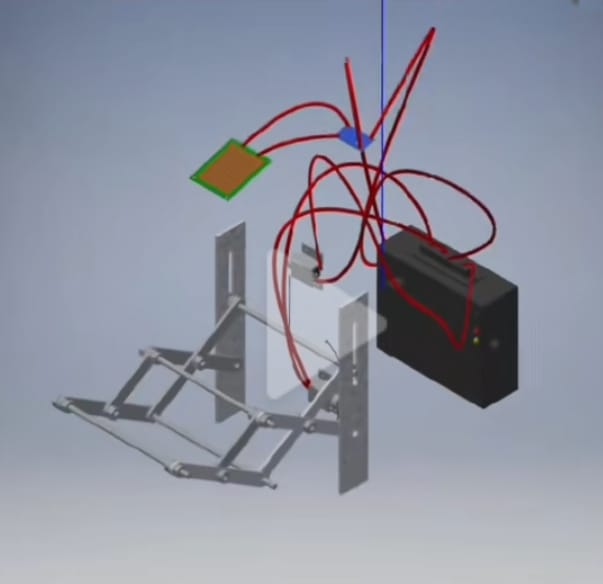
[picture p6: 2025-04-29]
Desain 3D/IMG-20250427-WA0001.jpg

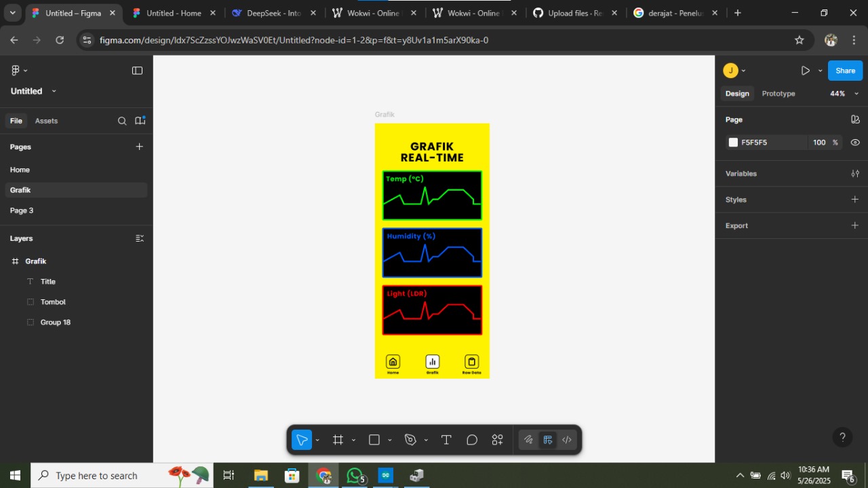
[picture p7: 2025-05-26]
Desain UI UX/Figma_GRAFIK.jpg

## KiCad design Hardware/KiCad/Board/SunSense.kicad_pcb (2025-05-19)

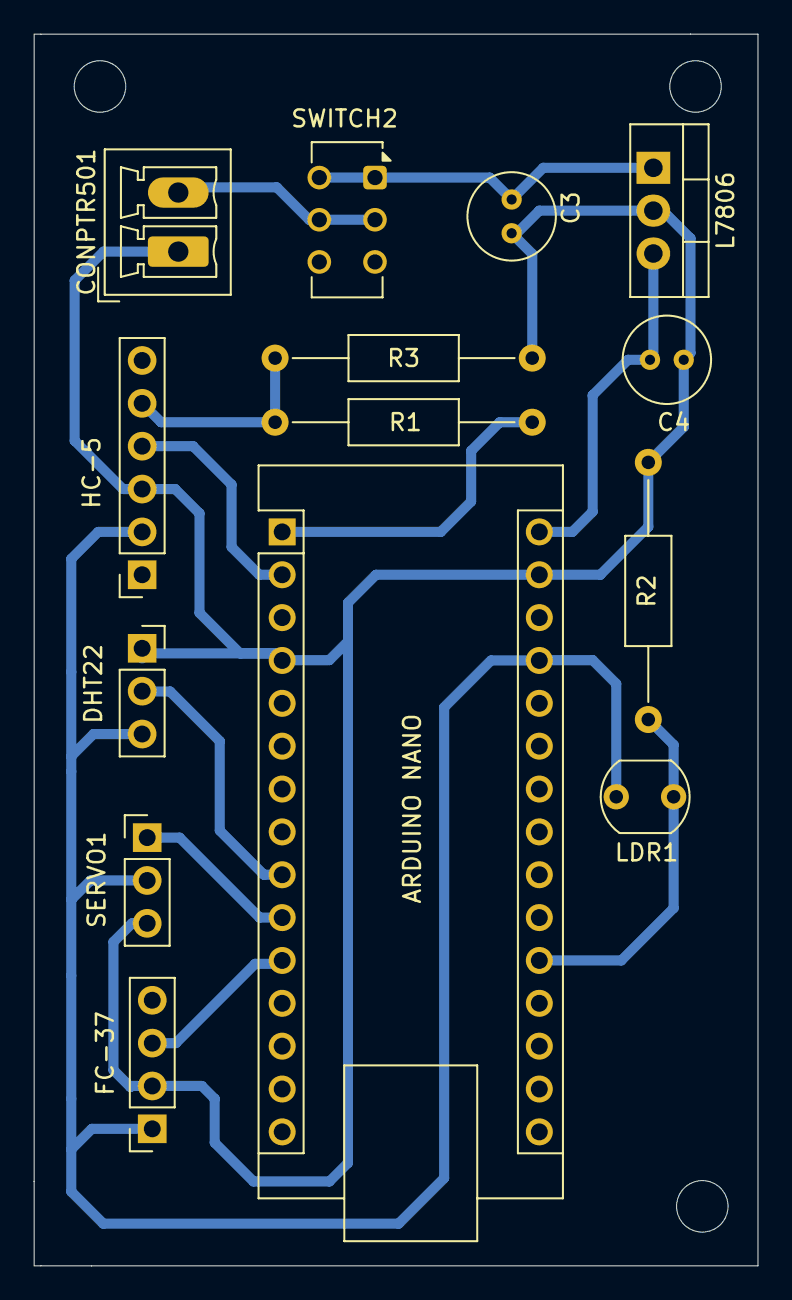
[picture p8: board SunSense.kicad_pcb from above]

Board: 2 copper layers, 42.9 x 73.0 mm, 14 parts (0 on the bottom side), 12 nets.

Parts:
A1: Arduino_Nano_v2.x; Arduino_Nano
C3, C4: C; C_Radial_D5.0mm_H5.0mm_P2.00mm
CONPTR501: CONNECTOR; PhoenixContact_MCV_1,5_2-G-3.5_1x02_P3.50mm_Vertical
DHT22: DHT22; PinSocket_1x03_P2.54mm_Vertical
FC-37: FC-37; PinSocket_1x04_P2.54mm_Vertical
HC-5: HC-05; PinSocket_1x06_P2.54mm_Vertical
L7806: L7805; TO-220-3_Vertical
LDR1: LDR07; R_LDR_5.1x4.3mm_P3.4mm_Vertical
R1, R2, R3: R; R_Axial_DIN0207_L6.3mm_D2.5mm_P15.24mm_Horizontal
SERVO1: Motor_Servo; PinHeader_1x03_P2.54mm_Vertical
SWITCH2: SS 12D00; SW_CK_JS202011CQN_DPDT_Straight

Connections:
5V: A1.27 (+5V), DHT22.3, FC-37.1, HC-5.2, LDR1.2, SERVO1.2 (+)
DHT22: A1.9 (D6), DHT22.2
FC37: A1.11 (D8), FC-37.3
GND: A1.4 (GND), A1.29 (GND), C3.2, C4.2, CONPTR501.1, DHT22.1, FC-37.2, HC-5.3, L7806.2 (GND), R2.2, R3.2, SERVO1.3 (-)
LDR: A1.20 (A1), LDR1.1, R2.1
unnamed: CONPTR501.2, SWITCH2.2
unnamed: HC-5.5, R1.1, R3.1
unnamed: C3.1, L7806.1 (IN), SWITCH2.1
RX: A1.1 (D1/TX), R1.2
SERVO: A1.10 (D7), SERVO1.1 (PWM)
TX: A1.2 (D0/RX), HC-5.4
VIN: A1.30 (VIN), C4.1, L7806.3 (OUT)

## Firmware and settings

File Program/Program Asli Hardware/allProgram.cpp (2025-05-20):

#include <Arduino.h>
#include <Servo.h>
#include <DHT.h>

// Pin Configuration
#define DHT_PIN 6
#define DHT_TYPE DHT22
#define LDR_PIN A1
#define RAIN_SENSOR_PIN 8
#define SERVO_PIN 7
#define MODE_BUTTON_PIN 3
#define CONTROL_BUTTON_PIN 2

const unsigned long DHT_READ_INTERVAL = 1000;
const int LDR_DARK = 300;
const int UPDATE_INTERVAL = 500;
const int DEBOUNCE_DELAY = 50;
const int HUMID_THRESHOLD = 70;

DHT dht(DHT_PIN, DHT_TYPE);
Servo myservo;

struct SensorData {
  float temperature = 0;
  float humidity = 0;
  int light;
  bool rain;
  bool decision;
} data;

bool manualMode = false;
bool manualDecision = false;

unsigned long lastUpdate = 0;
unsigned long lastModeButtonPress = 0;
unsigned long lastControlButtonPress = 0;

// Fungsi gerakan servo halus
void smoothServoMove(int targetAngle) {
  int currentAngle = myservo.read();
  if (currentAngle == targetAngle) return;

  int step = (currentAngle < targetAngle) ? 1 : -1;
  for (int angle = currentAngle; angle != targetAngle; angle += step) {
    myservo.write(angle);
    delay(10);  // Sesuaikan kecepatan
  }
  myservo.write(targetAngle);  // Pastikan posisi akhir tepat
}

void updateSensors() {
  static unsigned long lastDHTRead = 0;
  if (millis() - lastDHTRead >= DHT_READ_INTERVAL) {
    float t = dht.readTemperature();
    float h = dht.readHumidity();
    if (!isnan(t)) data.temperature = t;
    if (!isnan(h)) data.humidity = h;
    lastDHTRead = millis();
  }

  data.light = analogRead(LDR_PIN);
  data.rain = digitalRead(RAIN_SENSOR_PIN) == LOW;
}

void makeAutomaticDecision() {
  bool raining = data.rain;
  bool dark = data.light < LDR_DARK;
  bool cold = data.temperature < 25.0;
  bool humid = data.humidity > HUMID_THRESHOLD;
  data.decision = !(raining || (dark && cold) || (dark && humid));
}

void controlServo() {
  int targetAngle = 0;
  if (manualMode) {
    targetAngle = manualDecision ? 45 : 0;
  } else {
    targetAngle = data.decision ? 45 : 0;
  }
  smoothServoMove(targetAngle);
}

void sendData() {
  Serial.print("<MODE:");
  Serial.print(manualMode ? "MANUAL" : "AUTO");
  Serial.print("|T:");
  Serial.print(data.temperature, 1);
  Serial.print("|H:");
  Serial.print(data.humidity, 1);
  Serial.print("|L:");
  Serial.print(data.light);
  Serial.print("|R:");
  Serial.print(data.rain ? "RAINING" : "DRY");
  Serial.print("|D:");
  Serial.println((manualMode ? manualDecision : data.decision) ? "OUT" : "IN");
  Serial.println(">");
}

void readModeButton() {
  static bool lastState = HIGH;
  bool currentState = digitalRead(MODE_BUTTON_PIN);
  if (lastState == HIGH && currentState == LOW) {
    if (millis() - lastModeButtonPress > DEBOUNCE_DELAY) {
      manualMode = !manualMode;
      lastModeButtonPress = millis();
    }
  }
  lastState = currentState;
}

void readControlButton() {
  static bool lastState = HIGH;
  bool currentState = digitalRead(CONTROL_BUTTON_PIN);
  if (manualMode && lastState == HIGH && currentState == LOW) {
    if (millis() - lastControlButtonPress > DEBOUNCE_DELAY) {
      manualDecision = !manualDecision;
      lastControlButtonPress = millis();
    }
  }
  lastState = currentState;
}

void handleSerialCommand() {
  if (Serial.available()) {
    char cmd = Serial.read();
    if (cmd == 'm') {
      manualMode = !manualMode;
      Serial.println(manualMode ? "MODE:MANUAL" : "MODE:AUTO");
    } else if (cmd == 'c' && manualMode) {
      manualDecision = !manualDecision;
      Serial.println(manualDecision ? "POS:OUT" : "POS:IN");
    }
  }
}

void setup() {
  Serial.begin(9600);
  dht.begin();
  myservo.attach(SERVO_PIN);
  myservo.write(0);  // Posisi awal

  pinMode(RAIN_SENSOR_PIN, INPUT);
  pinMode(MODE_BUTTON_PIN, INPUT_PULLUP);
  pinMode(CONTROL_BUTTON_PIN, INPUT_PULLUP);
}

void loop() {
  readModeButton();
  readControlButton();
  handleSerialCommand();

  if (millis() - lastUpdate > UPDATE_INTERVAL) {
    updateSensors();
    if (!manualMode) {
      makeAutomaticDecision();
    }
    controlServo();
    sendData();
    lastUpdate = millis();
  }
}

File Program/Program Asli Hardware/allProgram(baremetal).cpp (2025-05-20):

#include <avr/io.h>
#include <avr/interrupt.h>
#include <util/delay.h>

#define F_CPU 16000000UL

// Pin Definitions
#define DHT_PIN     PB0     // Digital pin 8 = PB0 pada ATmega328P
#define RAIN_PIN    PD2     // Pin 8
#define MODE_BUTTON PD3     // Tombol mode (pin 3)
#define CTRL_BUTTON PD4     // Tombol control (pin 2)
#define SERVO_PIN   PB1     // OC1A (Pin 9)

// Servo PWM
#define MIN_PULSE   1000    // Mikrodetik
#define MAX_PULSE   2000
#define SERVO_DEG_0   MIN_PULSE
#define SERVO_DEG_45 ((MIN_PULSE + MAX_PULSE) / 2) // ~1500 us

// Thresholds
#define LDR_DARK_THRESHOLD 300
#define HUMIDITY_THRESHOLD 70

// Delay for DHT communication
void dht_delay_us(uint16_t us) {
    while (us--) _delay_us(1);
}

// ========== USART Functions ==========
void uart_init() {
    UBRR0H = (uint8_t)(103 >> 8); // 9600 bps
    UBRR0L = (uint8_t)(103);
    UCSR0B = (1 << TXEN0);
    UCSR0C = (1 << UCSZ01) | (1 << UCSZ00); // 8-bit data
}

void uart_transmit(char c) {
    while (!(UCSR0A & (1 << UDRE0)));
    UDR0 = c;
}

void uart_print(const char *str) {
    while (*str) uart_transmit(*str++);
}

void print_num(int num) {
    char buffer[10];
    itoa(num, buffer, 10);
    uart_print(buffer);
}

// ========== ADC Functions ==========
void adc_init() {
    ADMUX = (1 << REFS0);                    // AVcc reference
    ADCSRA = (1 << ADEN) | (1 << ADPS2);     // Enable ADC, prescaler 16
}

uint16_t adc_read(uint8_t channel) {
    ADMUX = (ADMUX & 0xF0) | (channel & 0x07);
    ADCSRA |= (1 << ADSC);
    while (ADCSRA & (1 << ADSC));
    return ADC;
}

// ========== Rain Sensor ==========
void rain_sensor_init() {
    DDRD &= ~(1 << RAIN_PIN); // Input
}

bool is_raining() {
    return !(PIND & (1 << RAIN_PIN));
}

// ========== DHT22 Bit-Banging ==========
bool dht_start() {
    DDRB |= (1 << DHT_PIN);          // Set as output
    PORTB &= ~(1 << DHT_PIN);        // Pull low
    _delay_ms(18);
    PORTB |= (1 << DHT_PIN);         // Pull high
    dht_delay_us(40);
    DDRB &= ~(1 << DHT_PIN);         // Set as input

    dht_delay_us(80);
    if ((PINB & (1 << DHT_PIN))) return false; // No response
    dht_delay_us(80);
    return true;
}

uint8_t dht_receive_byte() {
    uint8_t byte = 0;
    for (uint8_t i = 0; i < 8; i++) {
        while (!(PINB & (1 << DHT_PIN))); // Wait for low
        dht_delay_us(40);
        if (PINB & (1 << DHT_PIN)) {
            byte |= (1 << (7 - i));
        }
        while (PINB & (1 << DHT_PIN)); // Wait for next bit
    }
    return byte;
}

bool dht_read(float *temp, float *humi) {
    if (!dht_start()) return false;

    uint8_t data[5];
    for (int i = 0; i < 5; i++) {
        data[i] = dht_receive_byte();
    }

    uint16_t checksum = data[0] + data[1] + data[2] + data[3];
    if (checksum != data[4]) return false;

    *humi = (data[0] << 8 | data[1]) / 10.0;
    *temp = (data[2] << 8 | data[3]) / 10.0;

    return true;
}

// ========== Servo Control ==========
void servo_init() {
    DDRB |= (1 << SERVO_PIN); // OC1A sebagai output
    TCCR1A = (1 << COM1A1) | (1 << WGM11); // Fast PWM, non-inverting
    TCCR1B = (1 << WGM13) | (1 << WGM12) | (1 << CS11); // Prescaler 8
    ICR1 = 4999; // Period = 20ms (50Hz)
}

void servo_set_pulse(uint16_t pulse) {
    OCR1A = pulse;
}

// ========== Button Debounce ==========
bool debounce(volatile uint8_t *port, uint8_t pin) {
    if (((*port) & (1 << pin)) == 0) {
        _delay_ms(50);
        if (((*port) & (1 << pin)) == 0) return true;
    }
    return false;
}

// ========== Main Function ==========
int main(void) {
    cli();

    uart_init();
    adc_init();
    servo_init();
    rain_sensor_init();

    DDRD &= ~((1 << MODE_BUTTON) | (1 << CTRL_BUTTON)); // Input
    PORTD |= (1 << MODE_BUTTON) | (1 << CTRL_BUTTON);   // Pull-up enable

    float temp = 0, humi = 0;
    bool manualMode = false;
    bool manualDecision = false;

    servo_set_pulse(SERVO_DEG_0); // Start position

    uint32_t lastUpdate = 0;
    const uint32_t updateInterval = 1000;

    sei();

    while (1) {
        // Baca tombol mode
        if (debounce(&PIND, MODE_BUTTON)) {
            manualMode = !manualMode;
            uart_print("MODE:");
            uart_print(manualMode ? "MANUAL\r\n" : "AUTO\r\n");
            _delay_ms(200);
        }

        // Baca tombol control (jika mode manual)
        if (manualMode && debounce(&PIND, CTRL_BUTTON)) {
            manualDecision = !manualDecision;
            uart_print("CONTROL:");
            uart_print(manualDecision ? "OUT\r\n" : "IN\r\n");
            _delay_ms(200);
        }

        // Update setiap 1 detik
        if (_delay_ms(1000)) { // dummy delay
            if (dht_read(&temp, &humi)) {
                int light = adc_read(1);
                bool raining = is_raining();

                // Keputusan otomatis
                bool dark = light < LDR_DARK_THRESHOLD;
                bool cold = temp < 25.0;
                bool humid = humi > HUMIDITY_THRESHOLD;
                bool autoDecision = !(raining || (dark && cold) || (dark && humid));

                bool currentDecision = manualMode ? manualDecision : autoDecision;
                servo_set_pulse(currentDecision ? SERVO_DEG_45 : SERVO_DEG_0);

                // Kirim ke serial
                uart_print("<T:");
                print_num((int)temp);
                uart_print("|H:");
                print_num((int)humi);
                uart_print("|L:");
                print_num(light);
                uart_print("|R:");
                uart_print(raining ? "RAINING" : "DRY");
                uart_print("|M:");
                uart_print(manualMode ? "MANUAL" : "AUTO");
                uart_print("|D:");
                uart_print(currentDecision ? "OUT" : "IN>\r\n");
            } else {
                uart_print("DHT ERROR\r\n");
            }
        }
    }
}

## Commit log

2025-05-02 Update allProgram.cpp
    Update Sensor DHT22 dan LDR (Rain Sensor pake push button)
2025-05-10 Buat Folder Asset
    buat folder aset yang kedepannya akan di buat gambar simulasi , video simulasi atau demo program
2025-05-10 Delete Program/Asset/Readme.md
    hapus file dummy untuk buat folder di awal
2025-05-10 Update README.md
    Membetulkan path gambar ke file yang ada di dalam folder aset
2025-05-11 Nambah Folder program GUI
    Nambah Folder program GUI untuk Penempatan program python untuk me monitoring data dari arduino nano
2025-05-11 Delete Program/Program GUI/readme.md
    hapus file dummy untuk buat folder program gui di awal , dan sekarang sudah ada isinya yaitu sunsense.py
2025-05-11 Add KiCad schematic file for circuit design
    This commit includes the main schematic file (.kicad_sch) created in KiCad for documenting and sharing the circuit design. This schematic serves as the base for PCB layout and collaboration.
    [SunSense.kicad_sch]
2025-05-11 Add KiCad PCB layout file (.kicad_pcb)
    Uploaded the PCB layout file generated from the schematic. This file contains the physical design of the circuit, including component placements and routing. Designed using KiCad for fabrication and 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
    [SunSense.kicad_pcb]
2025-05-11 Add 3D render image of PCB layout
    Uploaded a rendered image of the PCB in 3D view from KiCad. This visual helps with presentation, documentation, and verifying component placement and orientation.
2025-05-11 Delete Hardaware/SunSense.kicad_sch
    Karena akan diganti dengan versi .png
    [SunSense.kicad_sch]
2025-05-11 Add KiCad Schematic file (.png)
    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
    [SunSense.kicad_sch]
2025-05-11 Create Folder and Sub-folder
    Menambahkan folder Kicad dan sub-folder Schematic
2025-05-11 Rename folder "Hardaware" to "Hardware"
    [SunSense.kicad_pcb, SunSense.kicad_sch]
2025-05-11 Menambahkan folder dan sub-folder
    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
2025-05-11 Add KiCad Schematic
    Berisi file .png dan juga file .sch dari KiCad
    [SunSense.kicad_sch]
2025-05-11 Create Folder KiCad
2025-05-11 Create Folder Schematic
2025-05-11 Add KiCad Schematic
    Berisi file .png dan juga .sch dari KiCad
    [SunSense.kicad_sch]
2025-05-11 Create folder Board
2025-05-11 Add KiCad Board
    Berisi file .png dan juga .pcb KiCad
    [SunSense.kicad_pcb]
2025-05-11 Add 3D Viewer from KiCad
    Berisi gambaran PCB bagian depan dan belakang.
2025-05-11 Benerin Gambar Simul biar fokus ke komponen yg di simulasikan
2025-05-11 Update README.md (nambah pin utk inisialisasi ke program)
2025-05-11 Update allProgram.cpp (ganti pin rain sensor dan ngasih penjelasan)
2025-05-11 Update README.md (nambahin tabel untuk penjelasan komponen di simulasi)
2025-05-18 Update allProgram.cpp ganti raindrop jadi sensor beneran
2025-05-19 Delete Hardware/KiCad/3D Design/3D Design from Board SunSense (behind).png
    Mengganti file dengan yang baru
2025-05-19 Add 3D Design PCB
    Berisi file .png
2025-05-19 Delete Hardware/KiCad/3D Design/3D Design from Board SunSense (front).png
    Mengganti dengan file baru
2025-05-19 Delete Hardware/KiCad/Board/Board SunSunse from KiCad.png
    Mengganti dengan yang baru
2025-05-19 Add PCB Layout Preview
    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
2025-05-19 Delete Hardware/KiCad/Board/SunSense.kicad_pcb
    mengganti dengan file baru
    [SunSense.kicad_pcb]
2025-05-19 Add File PCB from KiCad
    Berisi file KiCad Board
    [SunSense.kicad_pcb]
2025-05-19 Delete Hardware/KiCad/Schematic/Schematic SunSense from KiCAD.png
    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
2025-05-19 Delete Hardware/KiCad/Schematic/SunSense.kicad_sch
    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
    [SunSense.kicad_sch]
2025-05-19 Create Schematic folder
2025-05-19 Add Schematic Files
    Berisi file .png dan .kicad_sch
    [SunSense.kicad_sch]
2025-05-19 Update README.md
    Memperbaiki koneksi pin
2025-05-20 Update allProgram.cpp (ganti pin)
